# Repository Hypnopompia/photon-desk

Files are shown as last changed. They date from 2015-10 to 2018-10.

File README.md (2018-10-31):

photon-desk
==============

Desk Controller (http://www.youtube.com/watch?v=VQ_Kc9S85WM "Desk Controller")

A wifi enabled adjustable height desk.

Using a Particle Photon, this project allows you to remotely control your [V3 GeekDesk](http://www.geekdesk.com/geekdesk-v3-frame-only) The V3 only comes with a simple up/down button panel and doesn't allow you to have any presets.

Using an HC-SR04 Ultrasonic distance sensor attached to the bottom of the desk and pointed at the floor, we can measure the height of the desk. Using a pair of opto-isolators tapped into the button panel we can control the desk. The buttons are connected to the desk controller through an rj45 cable. This allows up to connect to the buttons without doing any permanant modifications to the desk itself.

This project gives you the ability to get and set the height of your desk (in centimeters) using the Particle's REST api

For a great compatible Mac app that works with this controller, checkout https://github.com/bdolman/StandUp

```
$ particle call Desk getHeight
97

$ particle call Desk setHeight 50
```

## Parts List

* (1) [GeekdeskV3 Controller PCB](https://github.com/Hypnopompia/photon-desk/tree/master/pcb)
* (1) [Particle Photon](https://store.particle.io/collections/photon)
* (1) [HC-SR04 Sonic Ping Sensor](http://www.amazon.com/s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)
* (1) [2-channel opto-isolator](https://www.digikey.com/product-detail/en/LTV-826/160-1362-5-ND/385832)
* (1) [Right-angle 4 pin female header](https://www.digikey.com/product-detail/en/PPTC041LGBN-RC/S5440-ND/775898)
* (2) [12 pin female header](https://www.digikey.com/product-detail/en/PPTC121LFBN-RC/S6100-ND/807231)
* (2) [220Ω resistors](https://www.digikey.com/product-detail/en/CFR-50JB-52-220R/220H-ND/1291)
* (2) [RJ45 8-pin connector](https://www.sparkfun.com/products/643)

## Assembly Instructions
Assembly instructions can be found here: [http://imgur.com/a/hMbX6](http://imgur.com/a/hMbX6)

## Geekdesk control panel rj45 pinout

* White (3) - GND
* Red (8) - Down Button (+5V)
* Brown (7) - Up Button (+5V)

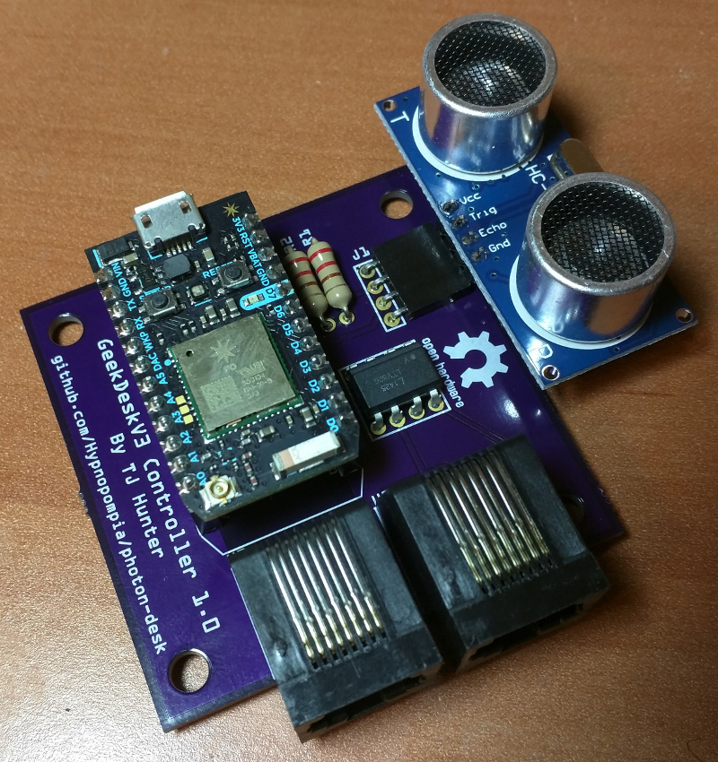
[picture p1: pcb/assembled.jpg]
Assembled Board View

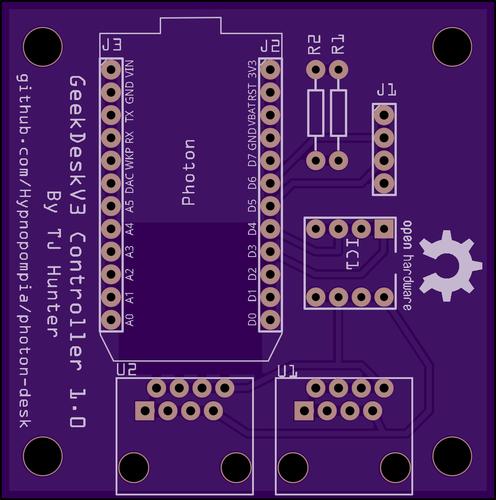
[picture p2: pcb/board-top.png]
Top Board View


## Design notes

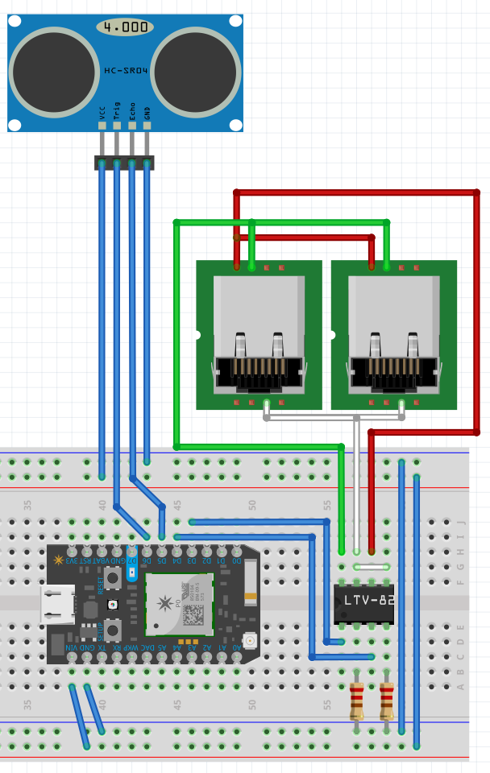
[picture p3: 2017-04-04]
pcb/schematic.png

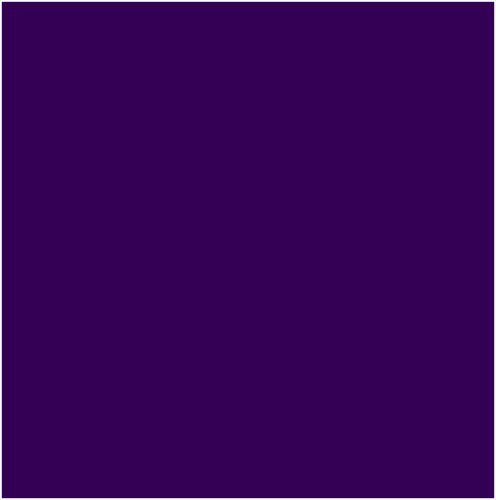
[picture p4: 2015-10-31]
pcb/bottom-silk-screen.png

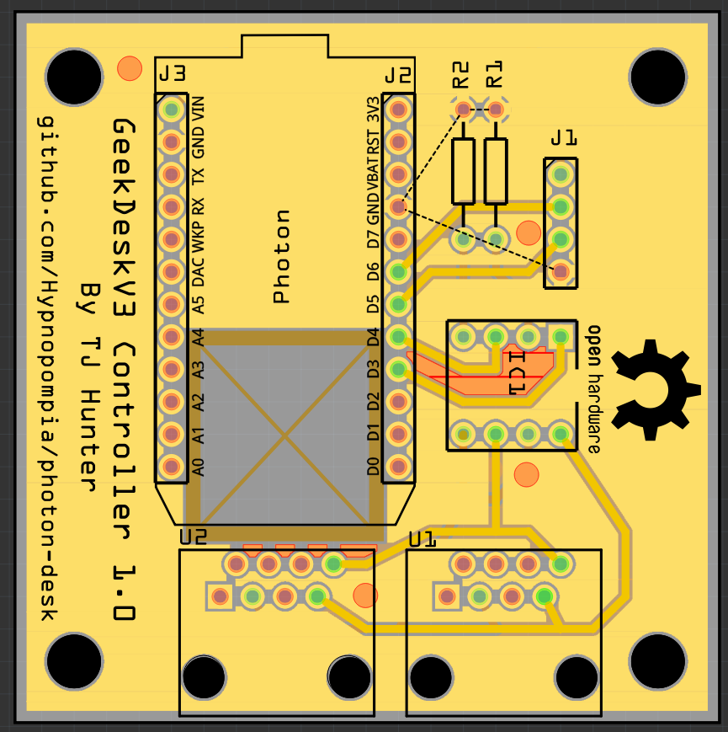
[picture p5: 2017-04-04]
pcb/pcb.png

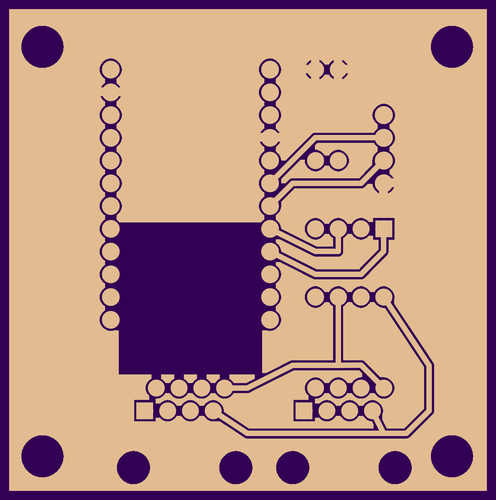
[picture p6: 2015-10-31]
pcb/top-layer.png

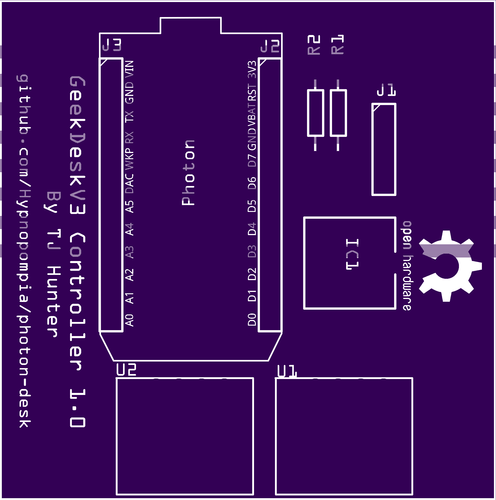
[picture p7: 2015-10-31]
pcb/top-silk-screen.png

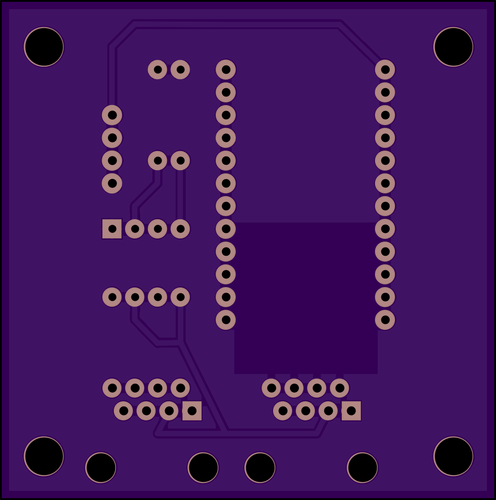
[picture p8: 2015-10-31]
pcb/board-bottom.png

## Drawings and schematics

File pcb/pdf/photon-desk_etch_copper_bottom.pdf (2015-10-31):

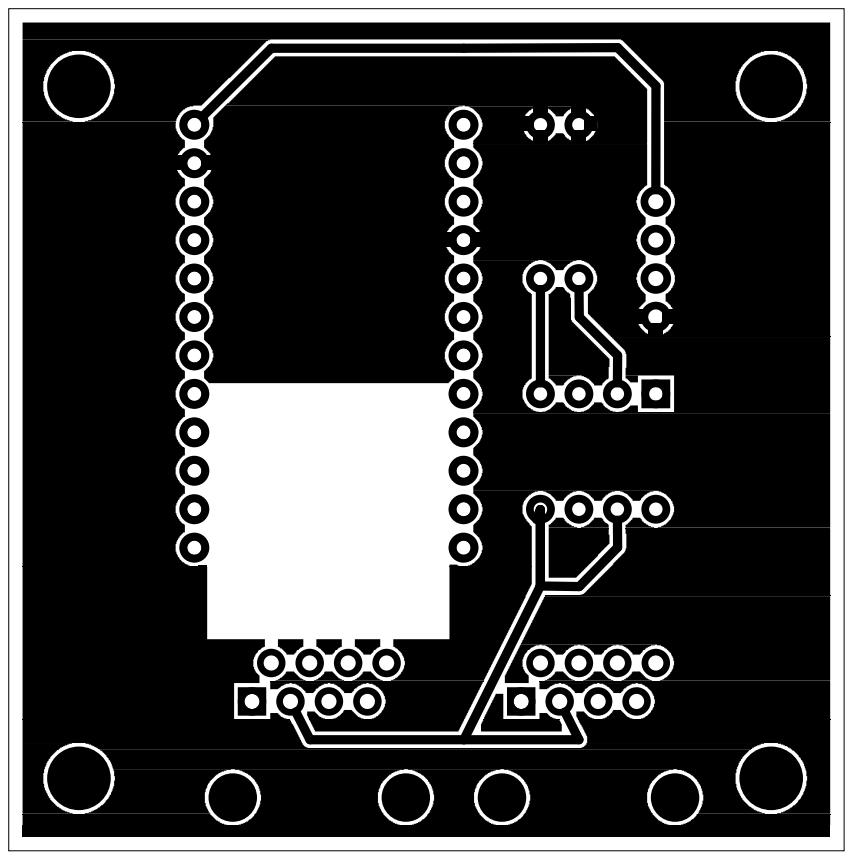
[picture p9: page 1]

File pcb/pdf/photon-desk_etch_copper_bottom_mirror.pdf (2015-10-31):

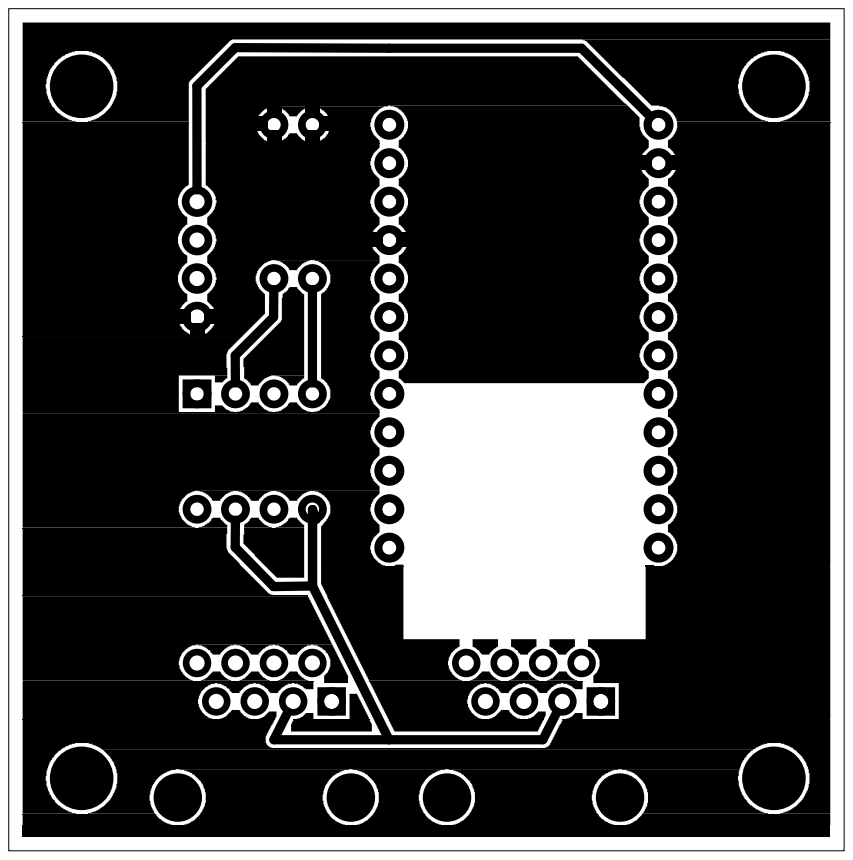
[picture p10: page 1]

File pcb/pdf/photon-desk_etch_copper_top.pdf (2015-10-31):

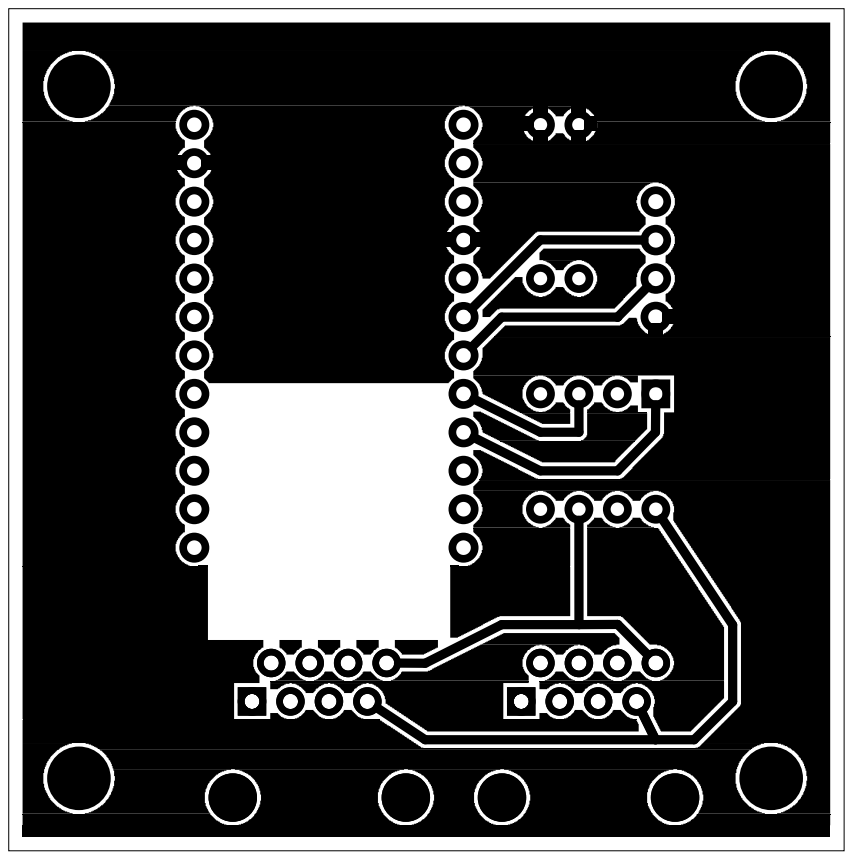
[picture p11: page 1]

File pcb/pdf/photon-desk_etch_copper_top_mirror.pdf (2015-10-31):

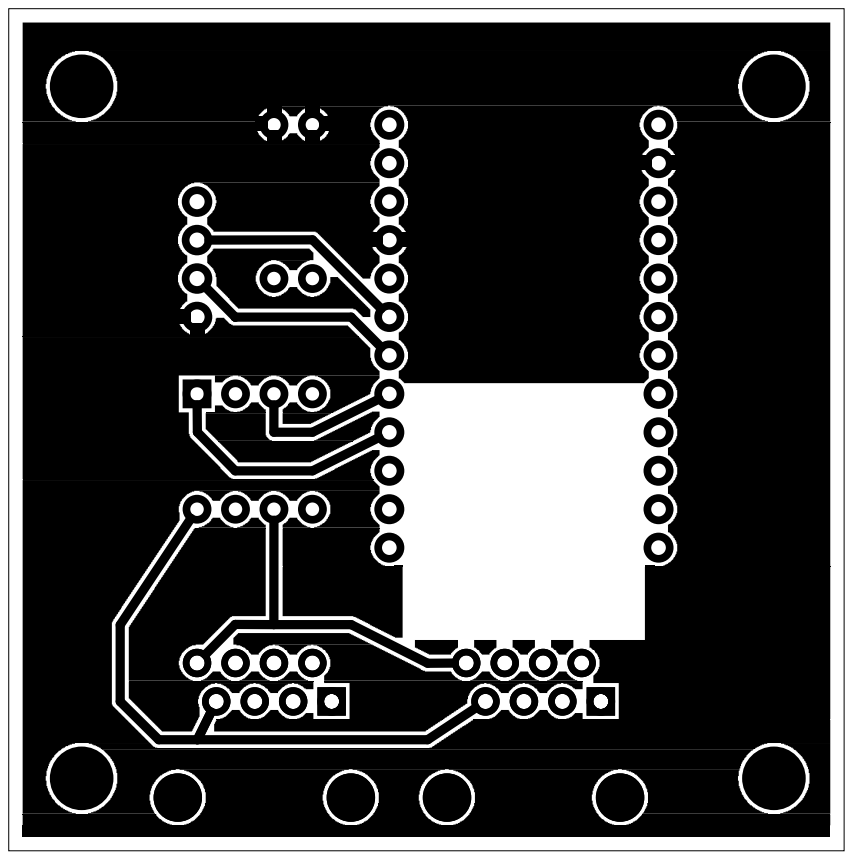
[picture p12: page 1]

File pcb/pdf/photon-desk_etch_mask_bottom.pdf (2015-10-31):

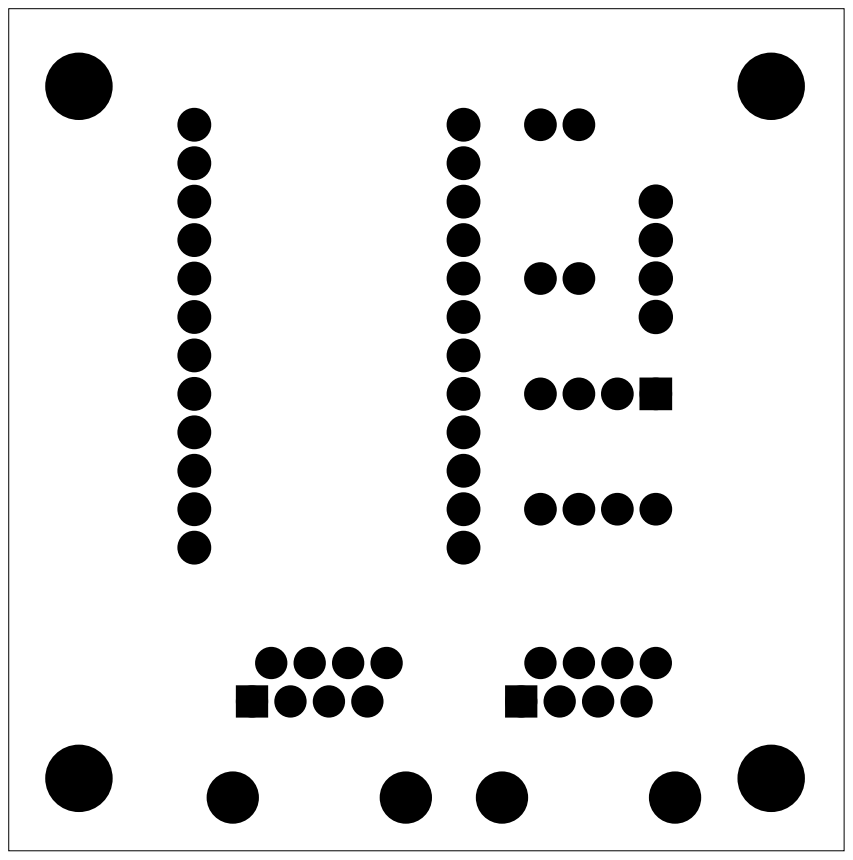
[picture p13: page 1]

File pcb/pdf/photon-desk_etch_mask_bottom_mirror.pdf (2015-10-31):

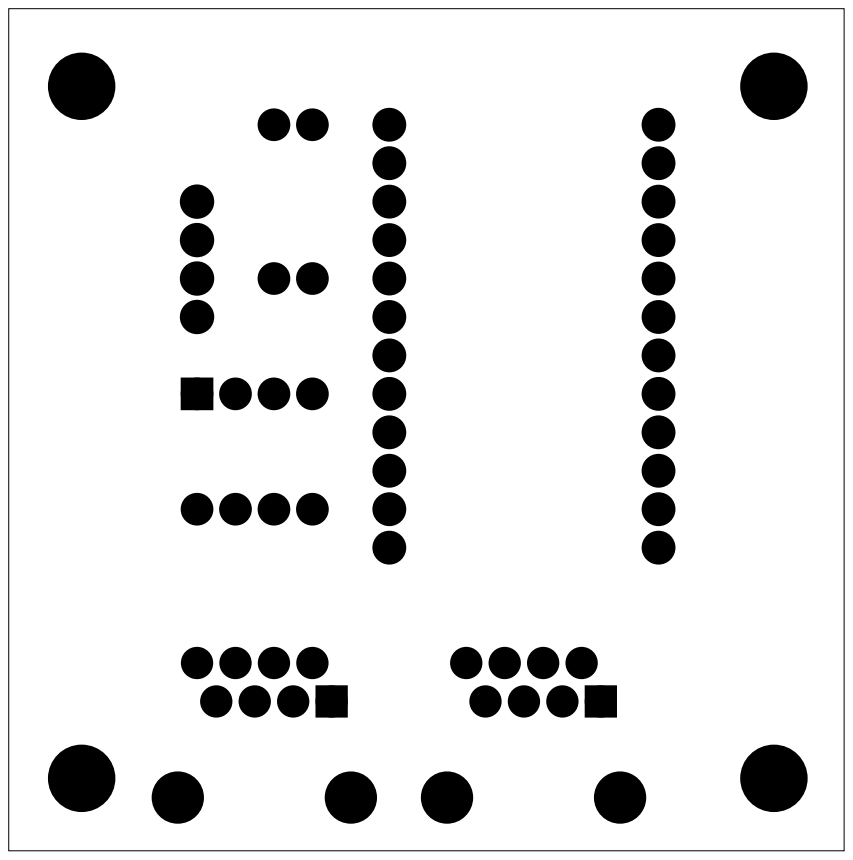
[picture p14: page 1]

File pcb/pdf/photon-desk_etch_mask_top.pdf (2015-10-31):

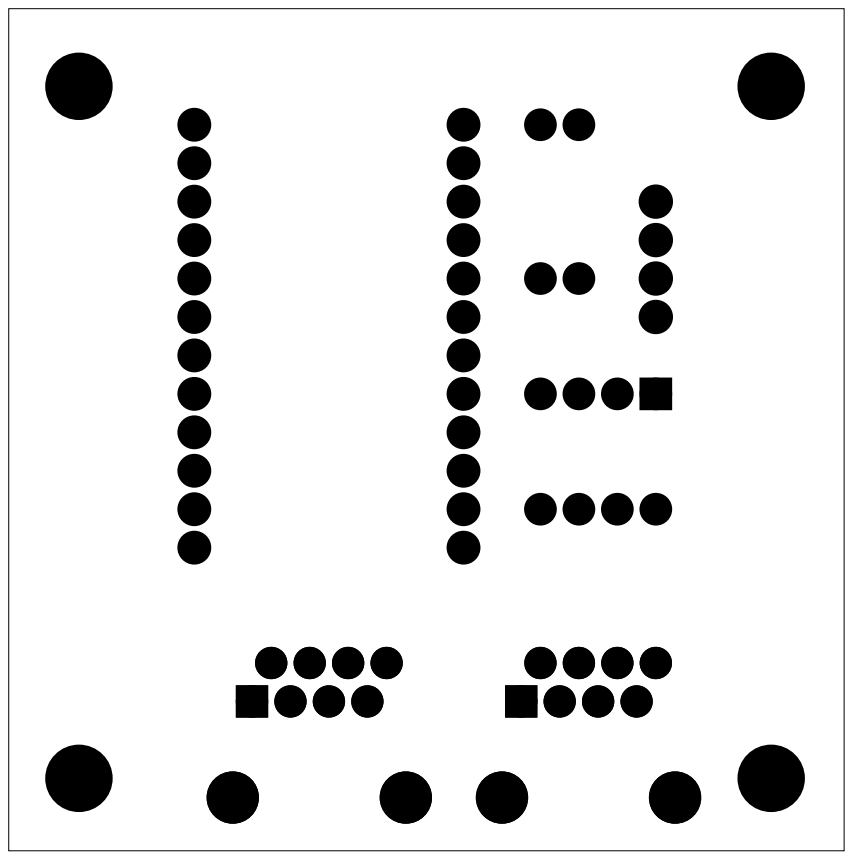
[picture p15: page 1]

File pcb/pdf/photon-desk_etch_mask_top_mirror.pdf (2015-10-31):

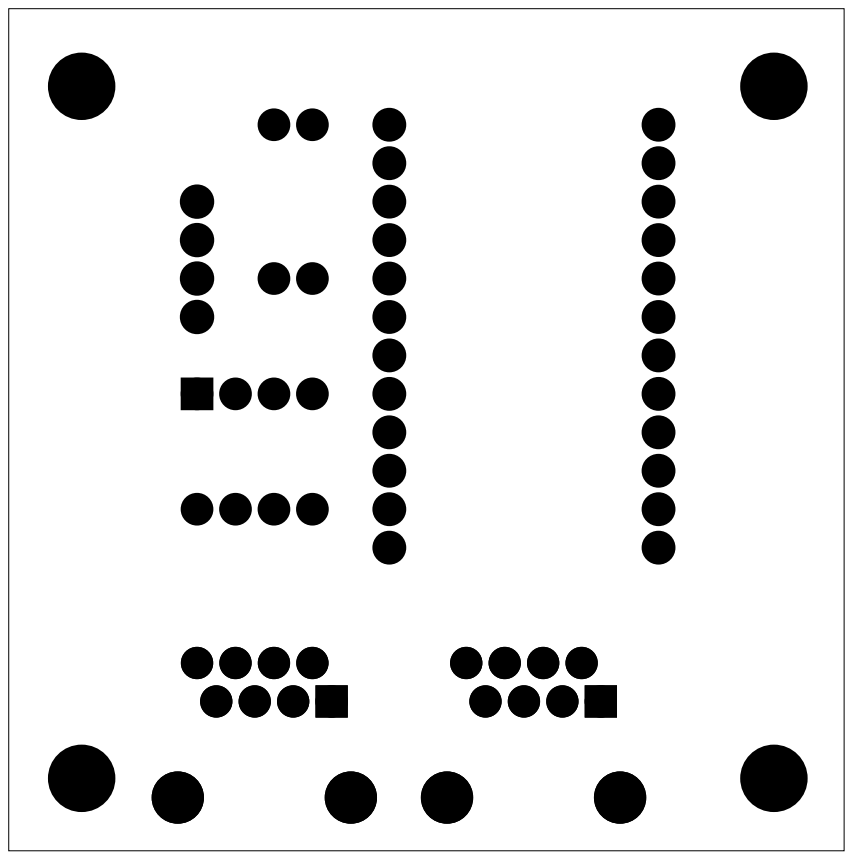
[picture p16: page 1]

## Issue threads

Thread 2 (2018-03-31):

Question: Geekdesk Controller

tommoor, 2018-03-31:
Sorry to file an issue, I couldn't find another way to get in touch with you. I am hoping to build this project and was wondering if you identified the controller that's in use by Geekdesk?

I have an Uplift Desk that also uses an RJ45 connector which appears to be made of off-the-shelf components manufactured by JIECAN. If Geekdesk uses the same supplier (seems likely?!) then I can probably follow your guide.

Thanks in advance, feel free to close this issue.

**Edit:** By the way, if you have any tindie kits left I'd be happy to buy one from you – hmu.

Hypnopompia, 2018-04-03:
Looking at the uplift desk controller on their website, I'm not sure it's compatible.

The geekdesk controller that I have is the simple Up/Down buttons. It doesn't communicate to the desk controller over any special type of data bus. Just simple on/off buttons. My wifi controller just emulates the button presses.

It looks like the uplift desk is more complicated than that, since it also includes a display for the current height of the desk, which indicates that it's passing more data along the rj45 connection. If you have a logic analyzer tool, you might be able to figure out why type of data bus it is and start from there.

Closed 2018-04-03.

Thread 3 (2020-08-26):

Question: Set Height Not Functioning

ddteeter, 2020-08-26:
Hey there! Great project -- I've had this PCB for years, but never found the time to assemble it. Not really expecting a response on a project so old, but I figure it doesn't hurt to ask!

I finally found time to assemble things and am working on an open source Electron menu-bar app, with the end goal of it being a pluggable standing desk analytics/goal setting/controller application (https://github.com/ddteeter/standing).

I have the basic functionality working, but am struggling with getting this controller to adjust the height of the desk. Electronics is not my strong suit, so I'm a bit lost there. I see through the Particle console that the appropriate commands are issued and the Photon logs the moveup event, but nothing happens and that's followed shortly thereafter by the movetimeout event. Measuring height does work appropriately, it's just the motion of the desk. Controlling the desk via the front panel works properly as well.

I checked connectivity using the schematic, and I feel like I have appropriate connectivity between all pins. I also checked connectivity across the socket just using a clipped lead (just to check if I had a bad joint or something somewhere) and it seems like everything is appropriate there as well. Also thought it might be a bad opto-isolator, so I've swapped through a couple with no luck still.

Any diagnostic tips for me?

Hypnopompia, 2020-08-26:
Hi there!

Glad to help if I can. It does sound like maybe something is wrong around the opto-isolator chip not triggering properly. Is it oriented in the PCB correctly?

We could probably try replacing the Photon firmware with something more simple to just get it to raise and lower the desk to try to troubleshoot it.

Another thing to try would be to short two of the pins on the desk side of the optoisolator (5 & 6 or 7 & 8) to see if that triggers the desk to raise or lower.

If that still doesn't work, could you possibly post some photos of your board and maybe I can see if I notice anything off.

ddteeter, 2020-08-27:
Thanks for the response, appreciate it so much!

Shorting out pins 5&6 or 7&8 on the desk side does move the desk down/up, so that side of the isolator does seem fine.

It does look to me like the isolator is oriented properly -- the dot (pin 1) is oriented closest to the ultrasonic sensor.

I will try and look into writing some simpler firmware this weekend to try and simplify things as you recommended. In the meantime, I'll post a photo of the PCB here shortly.

ddteeter, 2020-08-27:
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

ddteeter, 2020-08-30:
So I've taken a stab at debugging this. Not knowing electronics super well, I could very well be trying things that may fry the circuit, but oh well :) Fun experimenting. I initially swapped out the optocoupler for a pair of LEDs. I tested first with simple firmware that just set either D3 or D4 to high continuously and verified the respective LED did light up. I then swapped the proper firmware back in, but with the LEDs still in place, and verified the proper LED did light up for the appropriate operation. So definitely eliminates the firmware and tells me the controller side of the circuit must at least all have good connectivity.

I then swapped the optocoupler back in and verified things were still not working. But then I probed with the LED while the moveup operation was running. Spanning pin 1 and 2, the LED did not line up. But if I spanned from pin 1 to ground on the particle, the LED would light up while the moveup operation was happening. Not totally sure what to make of this yet, guess I need to read up more on circuits and the optocoupler. Am I not making it over some sort of voltage hump or something?

ddteeter, 2020-08-31:
I did verify with the diode tester on my DMM that the input side of the optoisolator seems to be working. Both 1&2 and 3&4 measure ~1.07V

Hypnopompia, 2020-08-31:
That does seem really odd. Seems like there's something wrong with the opto isolator. I don't remember what the input voltage on the optoisolator should be, but I could measure a known working board and find out. 1.07V sounds like it might be a little low to me, but I'd have to check.

If your multimeter has a continuity testing setting, you could try putting that at the 5&6 or 7&8 pins and see if it ever closes the circuit. If not, then it does sound like a problem with the optoisolator as long as that voltage is correct.

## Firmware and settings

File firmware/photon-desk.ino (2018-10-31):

/**
 ******************************************************************************
 * @file     photon-desk.cpp
 * @authors  TJ Hunter
 * @version  V1.0.0
 * @date     22-Oct-2015
 * @brief    Adjust the height of your geekdesk over WiFi using a Particle Photon
 ******************************************************************************
  Copyright (c) 2015 TJ Hunter.  All rights reserved.
  This library is free software; you can redistribute it and/or
  modify it under the terms of the GNU Lesser General Public
  License as published by the Free Software Foundation, either
  version 3 of the License, or (at your option) any later version.
  This library is distributed in the hope that it will be useful,
  but WITHOUT ANY WARRANTY; without even the implied warranty of
  MERCHANTABILITY or FITNESS FOR A PARTICULAR PURPOSE.  See the GNU
  Lesser General Public License for more details.
  You should have received a copy of the GNU Lesser General Public
  License along with this library; if not, see <http://www.gnu.org/licenses/>.
 ******************************************************************************
 */

#include "application.h"

#define trigPin D6 // Trig pin on the HC-SR04
#define echoPin D5 // Echo pin on the HC-SR04
#define upPin   D3 // Pin connected to the Up button on the smartdesk via an opto-isolator
#define downPin D4 // Pin connected to the Down button on the smartdesk via an opto-isolator

uint32_t lastCm, targetCm;
bool movingUp, movingDown;

uint32_t readings[10];
uint32_t readingIndex = 0;

unsigned long lastPingTime = 0;    // When we're not moving, we want to ping once per second to watch for manual movement.
unsigned long lastPublishTime = 0; // Keep track of when we last published and event so we don't flood
unsigned long movingStartTime;     // Keep track of when we started moving so we can timeout
unsigned long movingTimeOut = 0;   // # of seconds; Stop trying to move after moving for this many seconds in case something bad happens
unsigned long deskSpeed = 3;       // 3cm per second

char publishString[40];

void setup() {
	Particle.function("getHeight", getHeight);
	Particle.function("setHeight", setHeight);

	// Initialize the HC-SR04
	pinMode(trigPin, OUTPUT);
	digitalWriteFast(trigPin, LOW);

	// Initialize the buttons
	pinMode(upPin, OUTPUT);
	pinMode(downPin, OUTPUT);
	stop();

	delay(50);
	Serial.begin(115200);
}

void loop() {
	uint32_t currentHeight;

	// Timeout Check
	if ( (movingUp || movingDown) && ( (millis() - movingStartTime) / 1000 >= movingTimeOut ) ) {
		Particle.publish("movetimeout", NULL, 60, PRIVATE);
		Serial.println("Timeout! Stop.");
		stop();
	}

	// Target height check
	if (movingUp || movingDown) {
		currentHeight = microsecondsToCentimeters(readPingSensor());

		if (currentHeight != 0) { // we got a valid reading

			// The desk takes about a cm to come to a full stop, so stop 1cm early
			if ( (movingUp   && currentHeight >= ( targetCm - 1) ) ||
			     (movingDown && currentHeight <= ( targetCm + 3) )
			) { // We've reached our target height. Stop everything!
				sprintf(publishString, "%d", targetCm);
				Particle.publish("targetreached", publishString, 60, PRIVATE);
				Serial.println("Target height reached. Stopping...");
				stop();
			}

		}
	}

	// When we're not moving, we want to ping once per second to watch for manual movement.
	if ( (!movingUp && !movingDown) && (millis() - lastPingTime > 1100) ) {
		readPingSensor();
		lastPingTime = millis();
	}
}

void goUp() {
	Particle.publish("movingup", NULL, 60, PRIVATE);
	Serial.print("Going up to ");
	Serial.println(targetCm);
	stop();
	digitalWrite(upPin, HIGH);
	movingUp = true;
	movingStartTime = millis();
}

void goDown() {
	Particle.publish("movingdown", NULL, 60, PRIVATE);
	Serial.print("Going down to ");
	Serial.println(targetCm);
	stop();
	digitalWrite(downPin, HIGH);
	movingDown = true;
	movingStartTime = millis();
}

void stop() {
	digitalWrite(upPin, LOW);
	digitalWrite(downPin, LOW);
	movingUp = false;
	movingDown = false;
}

uint32_t getHeight(String command) {
	lastCm = 0; // Force a debug print to Serial
	return microsecondsToCentimeters(readPingSensor());
}

int setHeight(String command) {
	uint32_t currentHeight = microsecondsToCentimeters(readPingSensor());
	targetCm = command.toInt();

	if (currentHeight == targetCm) {
		Serial.println("Target and current heights are the same.");
	} else {
		// Calculate the distance we need to travel and using the known
		// travel speed of the desk, set a more appropriate timeout rather than hardcoding it.

		if (currentHeight > targetCm) {
			movingTimeOut = (currentHeight - targetCm) / deskSpeed;
			goDown();
		} else if (currentHeight < targetCm) {
			movingTimeOut = (targetCm - currentHeight) / deskSpeed;
			goUp();
		}

		movingTimeOut += 2; // It takes a bit to get up to speed

		Serial.print("Timeout in ");
		Serial.print(movingTimeOut);
		Serial.println(" seconds.");
	}


	return 1;
}

uint32_t avgReading() {
	uint32_t sum = 0, nonZero = 0, avg = 0;;
	for (uint32_t i = 0; i < 10; i++) {
		if (readings[i] > 0) nonZero++;
		sum += readings[i];
	}

	if (sum > 0 && nonZero > 0) {
		avg = sum / nonZero;
	}

	return avg;
}

uint32_t readPingSensor() {
	uint32_t duration, trycount, cm, avg;
	uint32_t haveGoodReading = 0;
	uint32_t readingThreshold = 58 * 4; // about 4cm

	trycount = 0;

	do {
		duration = ping();
		cm = microsecondsToCentimeters(duration);

		// less than 54cm or more than 120cm is likely an error.
		if (cm >= 54 && cm <= 120) {
			readings[readingIndex++] = duration;
			if (readingIndex >= 10) readingIndex = 0;

			// Do some smoothing on the readings to throw out outliers.
			avg = avgReading();

			// A reading more than 4cm from the average is probably also a bad reading.
			if (avg == 0 || abs(duration - avg) < readingThreshold ) {
				haveGoodReading = 1;
				Serial.print(".");
			} else {
				delay(50);
				Serial.print("o");
			}

		} else {
			delay(50);
			Serial.print("x");
		}

	} while ( ( !haveGoodReading ) && trycount++ < 25);

	Serial.print("  ");

	if (haveGoodReading == 0) {
		Serial.print("Bad reading. Avg: ");
		Serial.print(avg);
		Serial.print(" Reading: ");
		Serial.println(duration);

		duration = 0;
		cm = 0;
	} else {
		Serial.print(cm);
		Serial.print("cm, ");
		Serial.print(duration);
		Serial.println("us");
	}

	sprintf(publishString, "%d", cm);

	if ( (movingUp || movingDown) && (millis() - lastPublishTime > 1000) ) {
		Particle.publish("height", publishString, 60, PRIVATE);
		lastPublishTime = millis();
	}

	/* Debugging output */
	if (cm != lastCm || (millis() - lastPublishTime) > 5000 ) {
		lastCm = cm;

		if ( (millis() - lastPublishTime > 1000) ) {
			Particle.publish("height", publishString, 60, PRIVATE);
			lastPublishTime = millis();
		}
	}

	return duration;
}

uint32_t ping() {
	uint32_t duration;
	pinMode(echoPin, INPUT);
	pinMode(trigPin, OUTPUT);

	// The sensor is triggered by a HIGH pulse of 10 or more microseconds.
	digitalWriteFast(trigPin, HIGH);
	delayMicroseconds(10);
	digitalWriteFast(trigPin, LOW);

	duration = pulseIn(echoPin, HIGH); // Time in microseconds to recieve a ping back on the echo pin

	return duration;
}

uint32_t microsecondsToInches(uint32_t microseconds)
{
  // According to Parallax's datasheet for the PING))), there are
  // 73.746 microseconds per inch (i.e. sound travels at 1130 feet per
  // second).  This gives the distance travelled by the ping, outbound
  // and return, so we divide by 2 to get the distance of the obstacle.
  // See: http://www.parallax.com/dl/docs/prod/acc/28015-PING-v1.3.pdf
  return microseconds / 74 / 2;
}

uint32_t microsecondsToCentimeters(uint32_t microseconds)
{
  // The speed of sound is 340 m/s or 29 microseconds per centimeter.
  // The ping travels out and back, so to find the distance of the
  // object we take half of the distance travelled.
  return microseconds / 29 / 2;
}

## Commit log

2015-10-28 added fritzing pcb designs
    [photon-desk.fzz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]
2015-10-29 moved a trace, increased timeout to compensate for desk startup speed
    [photon-desk.fzz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]
2015-10-31 updated pcb, ubuntu scripts
2015-11-13 added assembled board photo
2015-11-16 updated pins to match the new circuit board
2015-11-16 skip printing stats when issuing move commands
2015-11-16 added pcb to parts list
2015-11-19 Add smoothing to sensor reading.
2017-04-04 reminder script, various tweaks
    [photon-desk-breadboard.fzz]
2017-04-04 fix for deciding how long the current session is. break when left desk
2017-05-12 include assembly instructions
2018-02-01 Remove broken link to tindie
    The board is no longer for sale on Tindie. closes #1
